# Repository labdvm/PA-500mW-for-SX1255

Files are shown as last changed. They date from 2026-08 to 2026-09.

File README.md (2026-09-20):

# PA-500mW-for-SX1255
500mW PA for SX1255 with TQP7M9106

# This PA you can use with SX1255 boards only without other PA's in the middle, dedicated for SXCEIVER and any other SX1255 boards without PA on it !!!
- This PA should be amplify ~400 mW clean Tetra signal.
# Board thickness is 0.8mm
- The L2,L3,L4 must be "wirewound" for better Q factor.
- The capacitors from the 100pF and below must be with 1% tolerance or better.
- The heatsink and cooler fan are mandatory !

Z32IT

You can order from here:

 <a href="https://www.pcbway.com/project/shareproject/500mW_PA_for_SX1255_boards_070e1752.html">PCB from PCBWay</a>

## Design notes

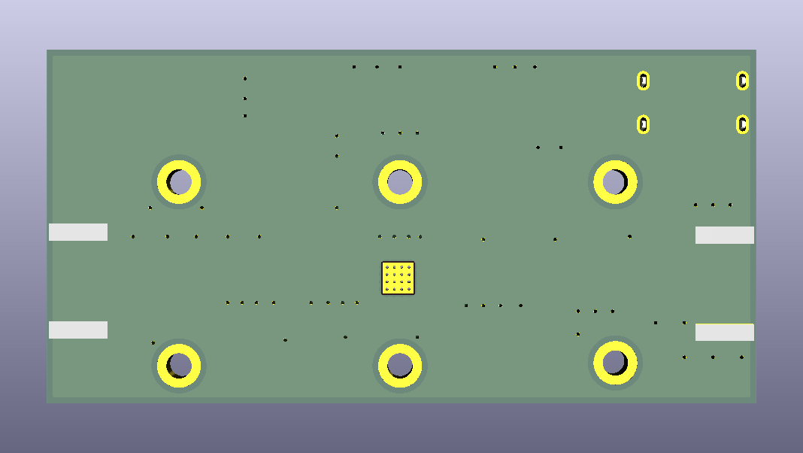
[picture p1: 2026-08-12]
PA 500mW for SX1255_b.png

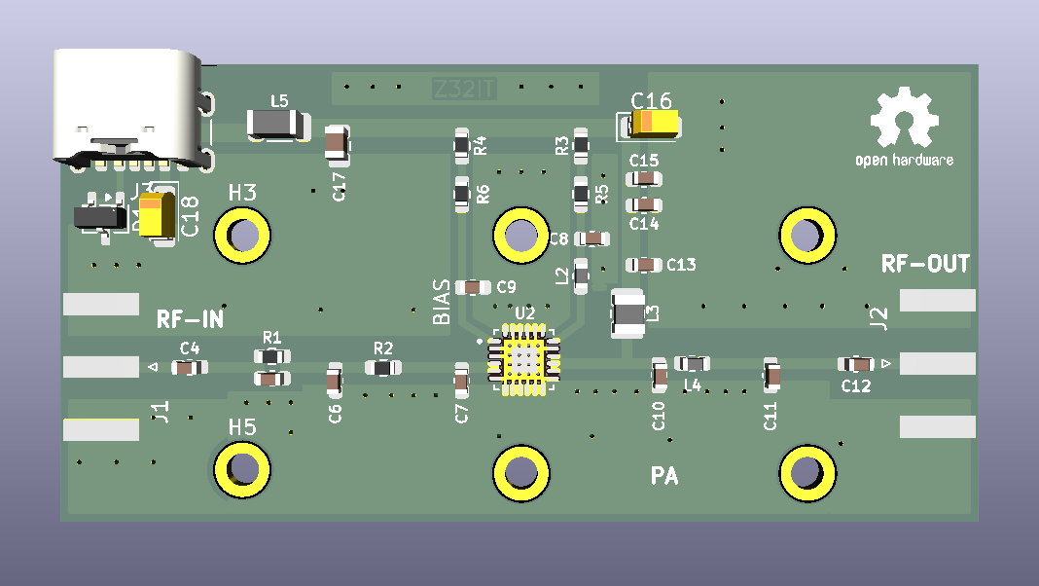
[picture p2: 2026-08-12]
PA 500mW for SX1255.png

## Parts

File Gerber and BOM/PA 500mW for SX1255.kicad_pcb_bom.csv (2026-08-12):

Designator | Quantity | Value | Footprint | Package | MPN | DNP | Mount_Type | Description | Manufacturer | Manufacturer Product Number | DigiKey Part Number | KiLib_Generator | Q min | Current | Value2
C10, C6 | 2 | 8p2 | C_0603_1608Metric |  |  |  | smt | Unpolarized capacitor, small symbol | YAGEO | CC0603BRNPO9BN8R2 | 311-3347-1-ND
C11 | 1 | 6p8 | C_0603_1608Metric |  |  |  | smt | Unpolarized capacitor, small symbol | YAGEO | CC0603BRNPO9BN6R8 | 311-3838-1-ND
C12 | 1 | 22p | C_0603_1608Metric |  |  |  | smt | Unpolarized capacitor, small symbol | YAGEO | CC0603FRNPO9BN220 | 311-3350-1-ND
C13, C15 | 2 | 1n | C_0603_1608Metric |  |  |  | smt | Unpolarized capacitor, small symbol | Murata Electronics | GRM1885C1H102JA01D | 490-1451-1-ND
C14, C4, C5, C8, C9 | 5 | 100p | C_0603_1608Metric |  |  |  | smt |  | YAGEO | CC0603FRNPO9BN101 | 311-3599-1-ND
C16 | 1 | 22u | CP_EIA-3216-18_Kemet-A |  |  |  | smt | Polarized capacitor, small symbol | KYOCERA AVX | TAJA226K010RNJ | 478-1663-1-ND | SMD_2terminal_chip_molded
C17 | 1 | 22p | C_0805_2012Metric |  |  |  | smt |  | YAGEO | CC0805FRNPO9BN220 | 311-4171-1-ND
C18 | 1 | 47u | CP_EIA-3216-18_Kemet-A |  |  |  | smt | Polarized capacitor, small symbol | KYOCERA AVX | F931A476KAA | 478-8223-1-ND | SMD_2terminal_chip_molded
C7 | 1 | 15p | C_0603_1608Metric |  |  |  | smt | Unpolarized capacitor, small symbol | YAGEO | AC0603FRNPO9BN150 | 13-AC0603FRNPO9BN150CT-ND
D1 | 1 | SP0502BAHT | SOT-23-3 |  |  |  | smt | TVS Diode Array, 5.5V Standoff, 2 Channels, SOT-23 package | Littelfuse Inc. | SP0502BAHTG | F2714CT-ND | package/gullwing
J3 | 1 | USB_C_Receptacle_PowerOnly_6P | USB_C_Receptacle_GCT_USB4125-xx-x_6P_TopMnt_Horizontal |  |  |  | smt | USB Power-Only 6P Type-C Receptacle connector | Shenzhen SHOUHAN Technology Co., Ltd | TYPE-C 6P | 6652-TYPE-C6PTR-ND
L2 | 1 | 68n | L_0603_1608Metric |  |  |  | smt | Inductor, small symbol | Murata Electronics | LQW18AS68NG0ZD | 490-15846-1-ND |  | 49.3 | 600 mA
L3 | 1 | 18n | L_1008_2520Metric |  |  |  | smt | Inductor, small symbol | Abracon LLC | AISC-1008HQ-18NG-T | 535-AISC-1008HQ-18NG-TTR-ND |  | 62 @ 350 MHz
L4 | 1 | 4n7 | L_0603_1608Metric |  |  |  | smt | Inductor, small symbol | Murata Electronics | LQW18AS4N7J00D | 490-LQW18AS4N7J00DCT-ND
L5 | 1 | 120 ohm/100MHz | L_1206_3216Metric |  |  |  | smt | Inductor with ferrite core, small symbol | Laird-Signal Integrity Products | LI1206H121R-10 | 240-2401-1-ND |  |  |  | 120 ohm/100MHz 1000mA
R1 | 1 | 51R | R_0603_1608Metric |  |  |  | smt | Resistor, small symbol | Vishay Dale | CRCW060351R0FKEA | 541-51.0HCT-ND
R2 | 1 | 4R3 | R_0603_1608Metric |  |  |  | smt | Resistor, small symbol | Vishay Dale | CRCW06034R30FKEA | 541-4.30HHCT-ND
R3, R4 | 2 | 270R | R_0603_1608Metric |  |  |  | smt | Resistor, small symbol | Vishay Dale | CRCW0603270RFKEAC | 541-5301-1-ND
R5, R6 | 2 | 10R | R_0603_1608Metric |  |  |  | smt | Resistor, small symbol | Vishay Dale | CRCW060310R0FKEA | 541-10.0HCT-ND | SMD_2terminal_chip_molded
U2 | 1 | TQP7M9106 | QFN50P400X400X90-25N |  |  |  | smt |  | Qorvo | TQP7M9106 | 2312-TQP7M9106CT-ND

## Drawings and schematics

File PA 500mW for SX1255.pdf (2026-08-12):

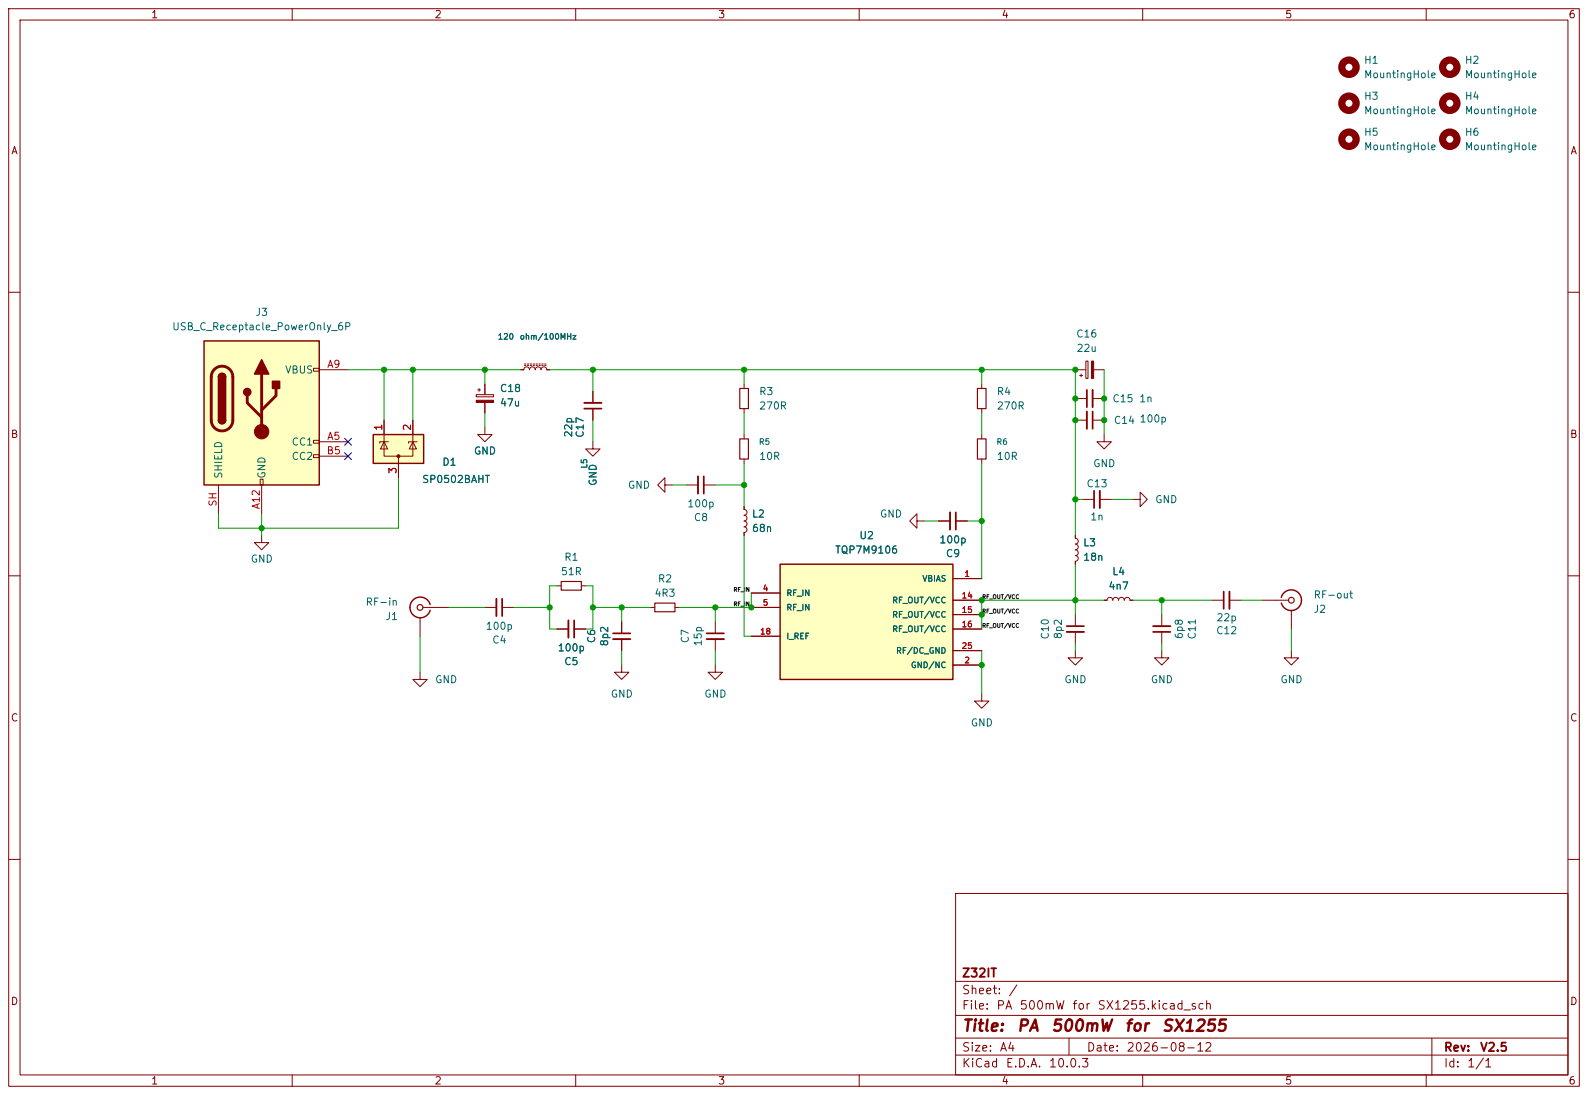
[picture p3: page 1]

Size: A4 | Rev: V2.5
KiCad E.D.A. 10.0.3 | Id: 1/1

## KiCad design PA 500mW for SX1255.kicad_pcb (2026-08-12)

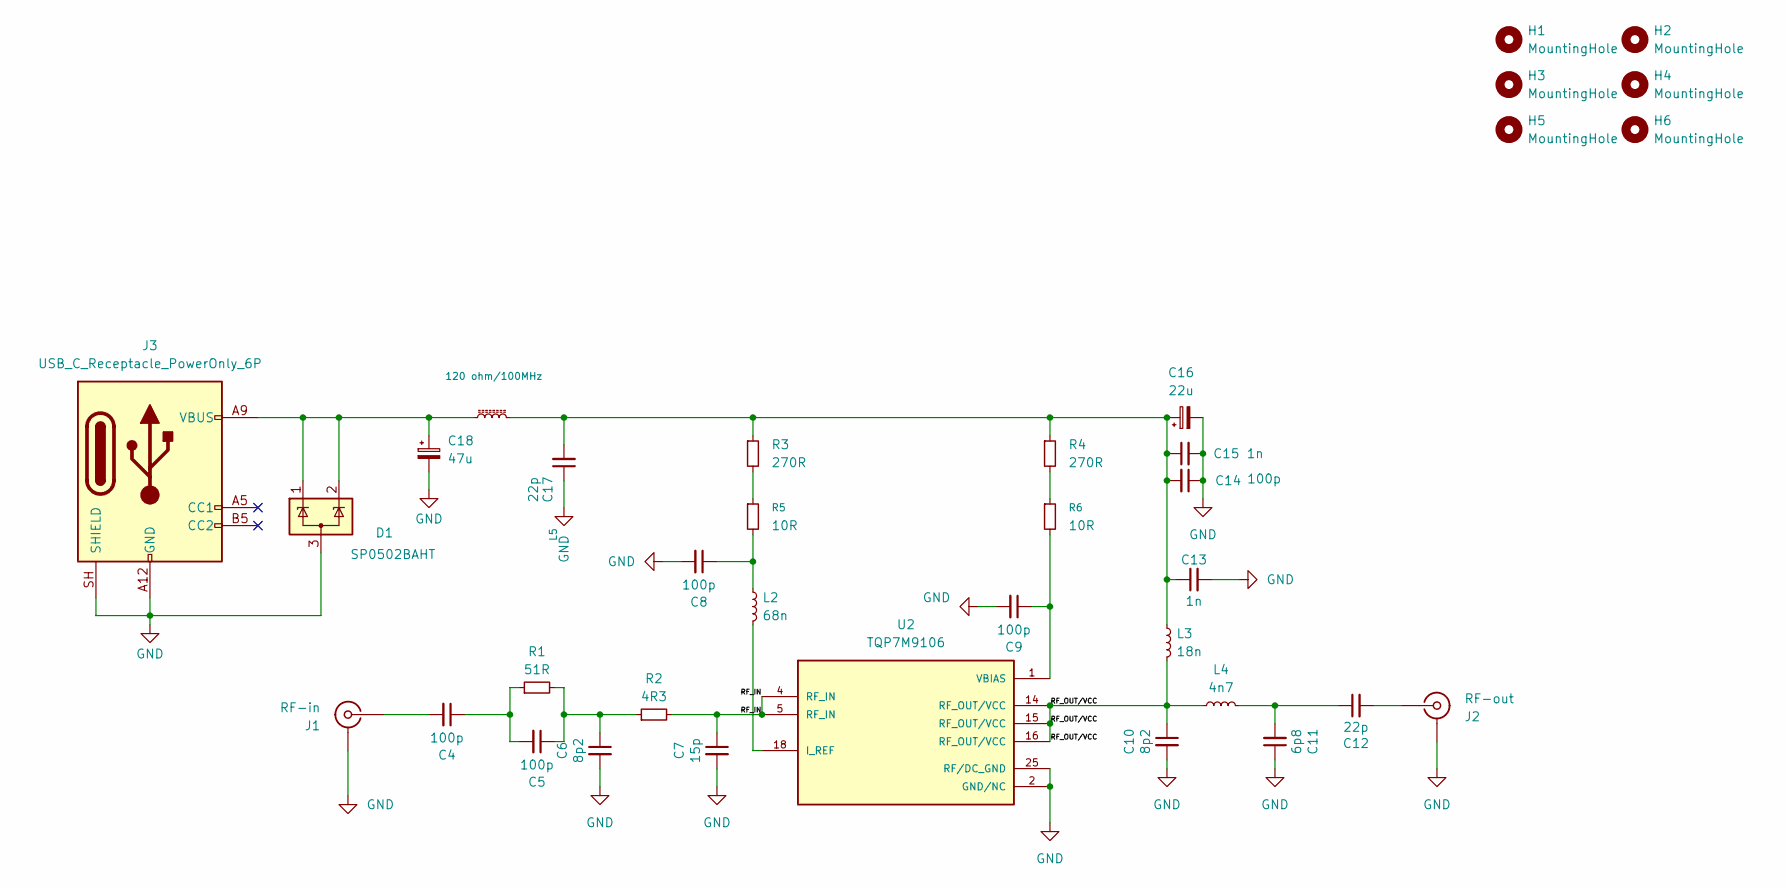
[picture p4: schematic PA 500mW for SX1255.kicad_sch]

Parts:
C4, C5, C8, C9, C14: 100p; C_0603_1608Metric; DigiKey Part Number 311-3599-1-ND
C6, C10: 8p2; C_0603_1608Metric; DigiKey Part Number 311-3347-1-ND
C7: 15p; C_0603_1608Metric; DigiKey Part Number 13-AC0603FRNPO9BN150CT-ND
C11: 6p8; C_0603_1608Metric; DigiKey Part Number 311-3838-1-ND
C12: 22p; C_0603_1608Metric; DigiKey Part Number 311-3350-1-ND
C13, C15: 1n; C_0603_1608Metric; DigiKey Part Number 490-1451-1-ND
C16: 22u; CP_EIA-3216-18_Kemet-A; DigiKey Part Number 478-1663-1-ND
C17: 22p; C_0805_2012Metric; DigiKey Part Number 311-4171-1-ND
C18: 47u; CP_EIA-3216-18_Kemet-A; DigiKey Part Number 478-8223-1-ND
D1: SP0502BAHT; SOT-23-3; DigiKey Part Number F2714CT-ND
H1, H2, H3, H4, H5, H6: MountingHole; MountingHole_2.2mm_M2_DIN965_Pad
J1: RF-in; SMA_Amphenol_132289_EdgeMount
J2: RF-out; SMA_Amphenol_132289_EdgeMount
J3: USB_C_Receptacle_PowerOnly_6P; USB_C_Receptacle_GCT_USB4125-xx-x_6P_TopMnt_Horizontal; DigiKey Part Number 6652-TYPE-C6PTR-ND
L2: 68n; L_0603_1608Metric; DigiKey Part Number 490-15846-1-ND
L3: 18n; L_1008_2520Metric; DigiKey Part Number 535-AISC-1008HQ-18NG-TTR-ND
L4: 4n7; L_0603_1608Metric; DigiKey Part Number 490-LQW18AS4N7J00DCT-ND
L5: 120 ohm/100MHz; L_1206_3216Metric; DigiKey Part Number 240-2401-1-ND
R1: 51R; R_0603_1608Metric; DigiKey Part Number 541-51.0HCT-ND
R2: 4R3; R_0603_1608Metric; DigiKey Part Number 541-4.30HHCT-ND
R3, R4: 270R; R_0603_1608Metric; DigiKey Part Number 541-5301-1-ND
R5, R6: 10R; R_0603_1608Metric; DigiKey Part Number 541-10.0HCT-ND
U2: TQP7M9106; QFN50P400X400X90-25N; DigiKey Part Number 2312-TQP7M9106CT-ND

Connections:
/RF_IN: C7.1, R2.2, U2.4 (RF_IN), U2.5 (RF_IN)
/RF_OUT/VCC: C10.1, L3.2, L4.1, U2.14 (RF_OUT/VCC), U2.15 (RF_OUT/VCC), U2.16 (RF_OUT/VCC)
GND: C6.2, C7.2, C8.2, C9.2, C10.2, C11.1, C13.2, C14.1, C15.2, C16.2, C17.1, C18.2, D1.3 (A), J1.2 (Ext), J2.2 (Ext), J3.A12 (GND), J3.B12 (GND), J3.SH (SHIELD), U2.2 (GND/NC), U2.3 (GND/NC), U2.6 (GND/NC), U2.7 (GND/NC), U2.8 (GND/NC), U2.9 (GND/NC), U2.10 (GND/NC), U2.11 (GND/NC), U2.12 (GND/NC), U2.13 (GND/NC), U2.17 (GND/NC), U2.19 (GND/NC), U2.20 (GND/NC), U2.21 (GND/NC), U2.22 (GND/NC), U2.23 (GND/NC), U2.24 (GND/NC), U2.25 (RF/DC_GND), U2.26 (RF/DC_GND)
unnamed: C4.1, C5.2, R1.1
unnamed: C5.1, C6.1, R1.2, R2.1
unnamed: C8.1, L2.1, R5.2
unnamed: C11.2, C12.1, L4.2
unnamed: C13.1, C14.2, C15.1, C16.1, C17.2, L3.1, L5.2, R3.1, R4.1
unnamed: C18.1, D1.1 (K), D1.2 (K), J3.A9 (VBUS), J3.B9 (VBUS), L5.1
unnamed: C4.2, J1.1 (In)
unnamed: C12.2, J2.1 (In)
unnamed: R3.2, R5.1
unnamed: R4.2, R6.1
unnamed: L2.2, U2.18 (I_REF)
unnamed: C9.1, R6.2, U2.1 (VBIAS)

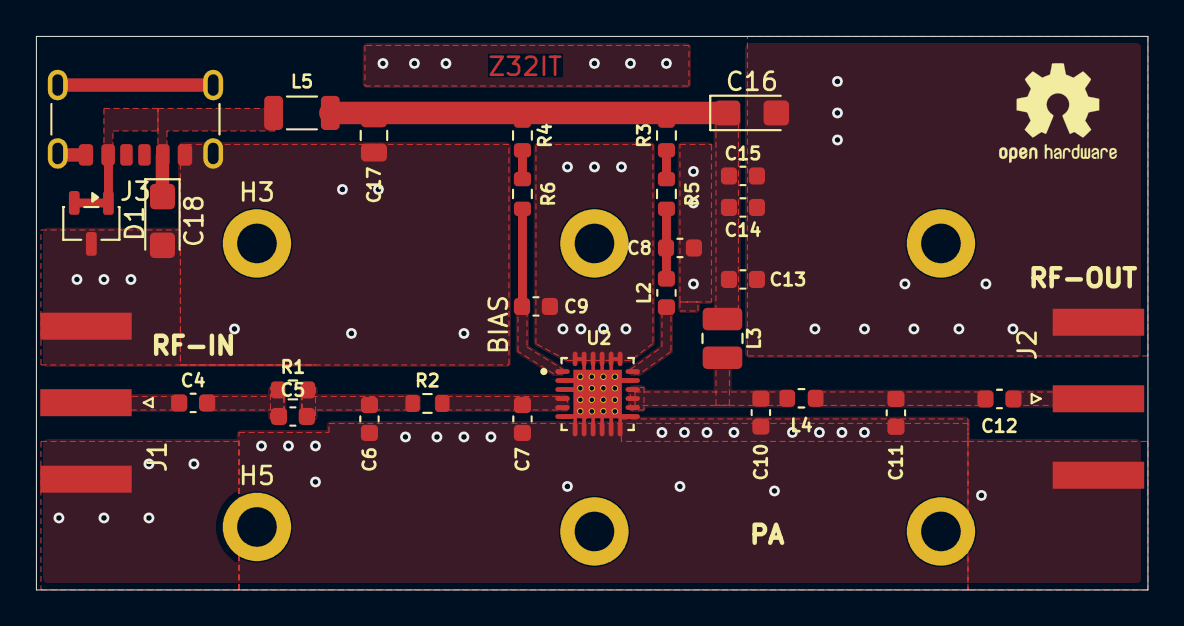
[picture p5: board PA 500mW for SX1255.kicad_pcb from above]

Board: 2 copper layers, 61.8 x 30.8 mm, 36 parts (0 on the bottom side), 15 nets.

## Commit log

2026-06-20 Update README with board thickness detail
    Added board thickness information to README.
2026-08-17 Add ordering link for Z32IT PCB
    Added ordering information for Z32IT PCB.
2026-08-17 Fix formatting of PCBWay link in README
2026-08-17 Add heatsink and cooler fan requirement to README
    Added a note about the necessity of heatsink and cooler fan.
2026-09-20 Update README with detailed PA usage instructions
    Clarified usage instructions for the PA with SX1255 boards.
